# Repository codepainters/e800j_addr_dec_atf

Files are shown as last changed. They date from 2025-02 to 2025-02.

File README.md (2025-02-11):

# PROM replacement for Elwro 800 Junior - ATF1502ASL SMD variant

Elwro 800 Junior uses two `SN74S474` 512x8 PROMs as IO and memory address decoders. These PROMs are increasingly difficult to obtain (and program), this project provides a plug-in replacement for both address decoders based on `ATF1502ASL` CPLD in `TQFP-44` package.

Note: there is [another version](https://github.com/codepainters/e800j_addr_dec_gal/) using `GAL16V8` in `DIL-20`. 

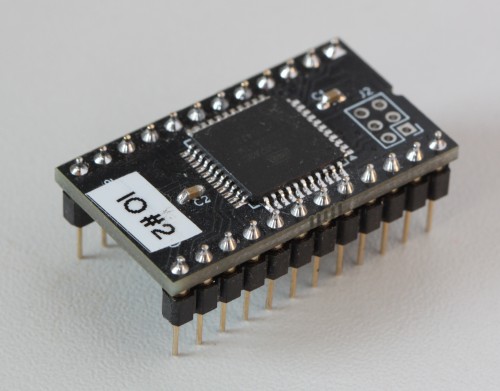
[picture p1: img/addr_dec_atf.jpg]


Hardware files:

* [pcb](pcb) - schematic/PCB project in KiCAD 8 format
* PDF schematics - [color](pdf/addr_dec.pdf) and [black&white](pdf/addr_dec_bw.pdf)
* [interactive BOM](addr_dec_atf_ibom.html) file (you have to download it and open locally)
* Gerber files (in a [jlcpcb](https://jlcpcb.com/)-compatible ZIP format):
  * [addr\_dec\_atf.zip](gerbers/addr_dec_atf.zip) - single PCB
  * [addr\_dec\_atf\_panel.zip](gerbers/addr_dec_atf_panel.zip) - two PCBs panelized

For bitstream files and programming instructions go to [bitstreams](bitstreams).

Under [src](src) you can find Quartus projects for I/O and MEM decoders (look there for details).

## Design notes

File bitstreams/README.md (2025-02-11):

# Bitstreams

The `ATF1502ASL` can be programmed using [OpenOCD](https://openocd.sourceforge.io/) (or any other software handling `.svf` files) with a supported `JTAG` interface. I have successfully programmed the chips using a `Segger J-Link v8` clone. 

`JTAG` connector `J2` pin-out (you have to provide +5V supply):

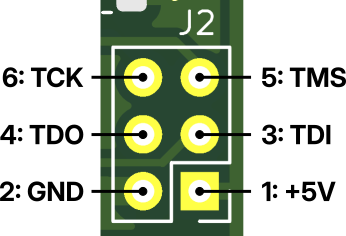
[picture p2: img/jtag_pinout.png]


## Files

The `ocd.sh` shell script is a wrapper around `openocd`, it takes a `svf` file name as its only parameter, e.g.:

```sh
$ ./ocd.sh addr_dec_io.svf
```

If you want to use other JTAG probe, edit the file accordingly (look for `-c "interface jlink"`).

The following `svf` files are available:
* `addr_dec_io.svf` - for I/O address decoder
* `addr_dec_mem.svf ` - for memory address decoder
* `atf1502asl_erase.svf` - helper file for erasing the `ATF1502ASL` chip

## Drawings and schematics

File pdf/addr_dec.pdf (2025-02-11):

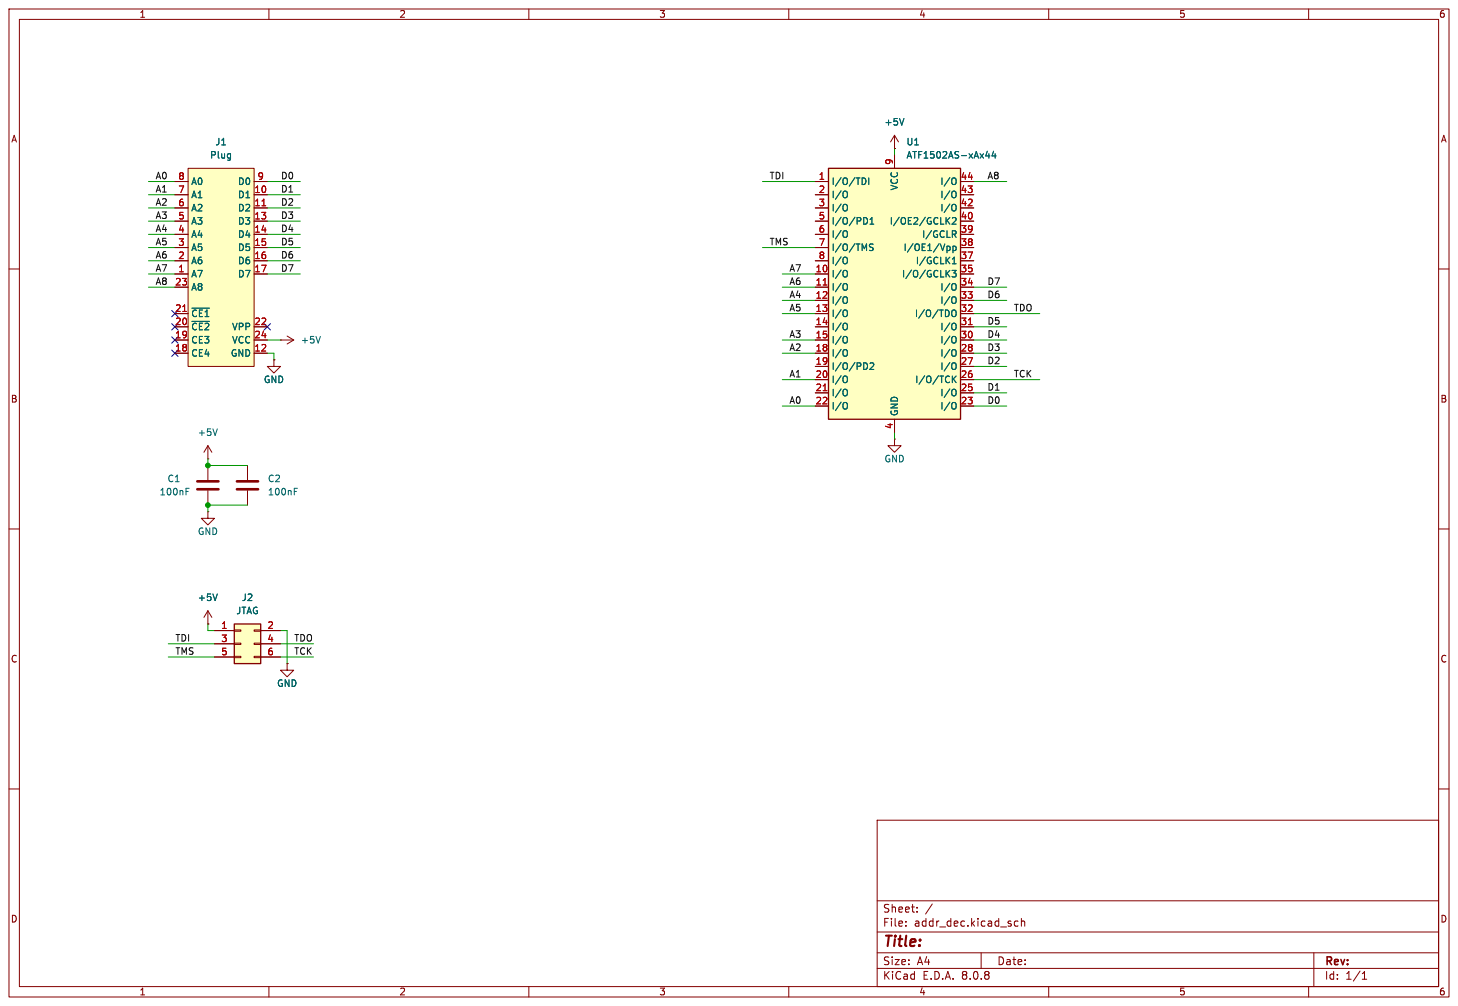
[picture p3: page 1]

Id: 1/1 Title: File: addr_dec.kicad_sch Sheet: / C2

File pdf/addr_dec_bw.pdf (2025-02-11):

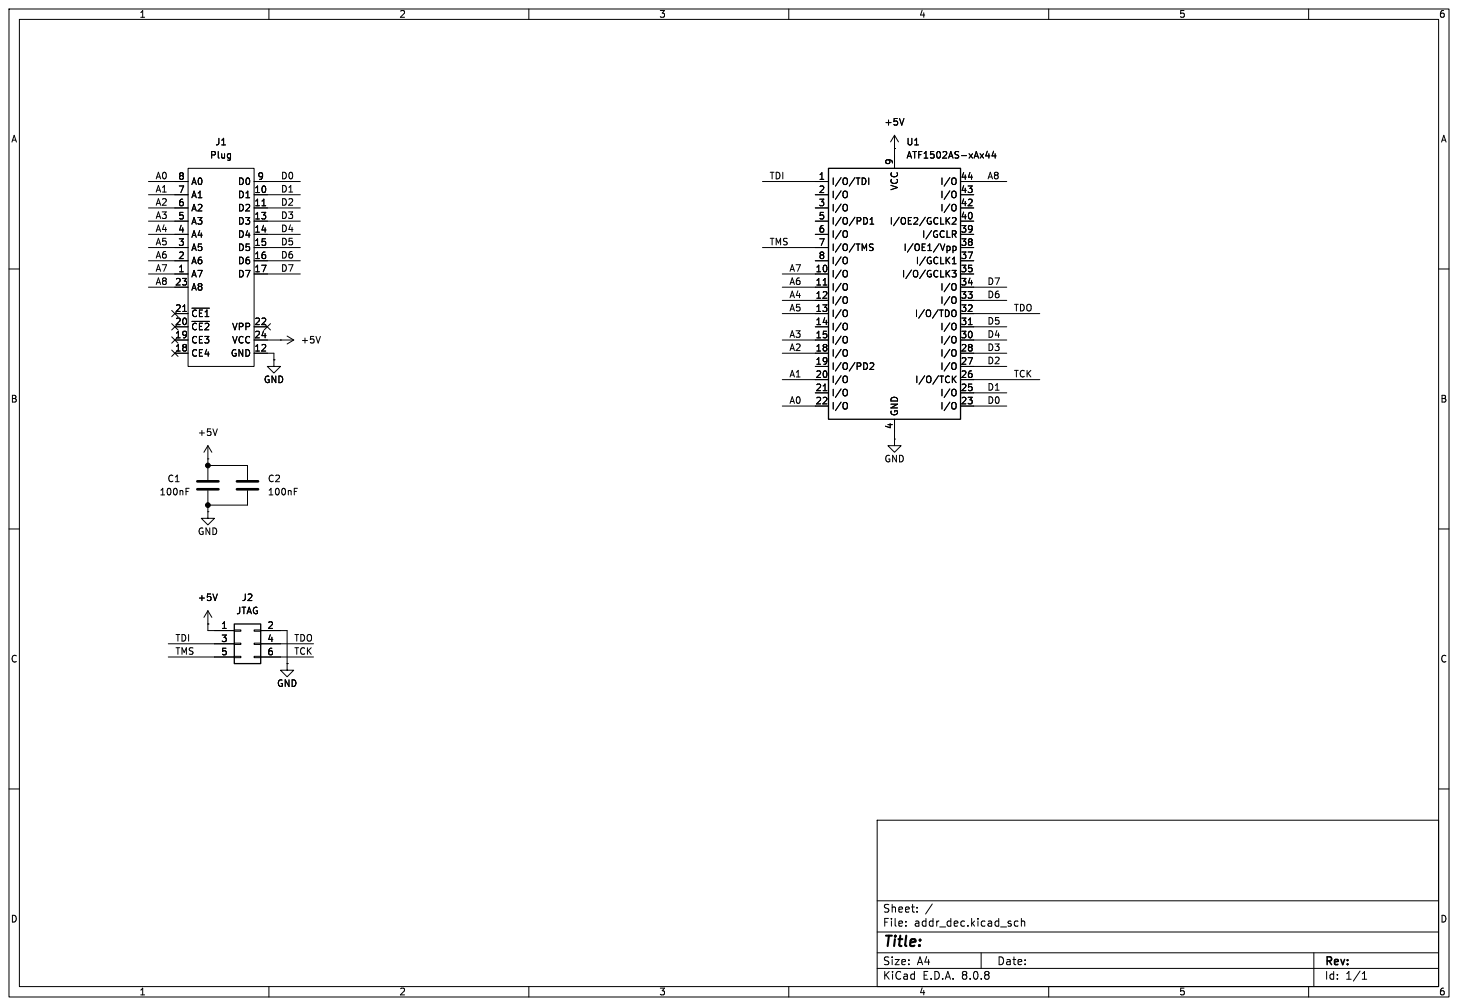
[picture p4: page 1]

Id: 1/1 Title: File: addr_dec.kicad_sch Sheet: / C2

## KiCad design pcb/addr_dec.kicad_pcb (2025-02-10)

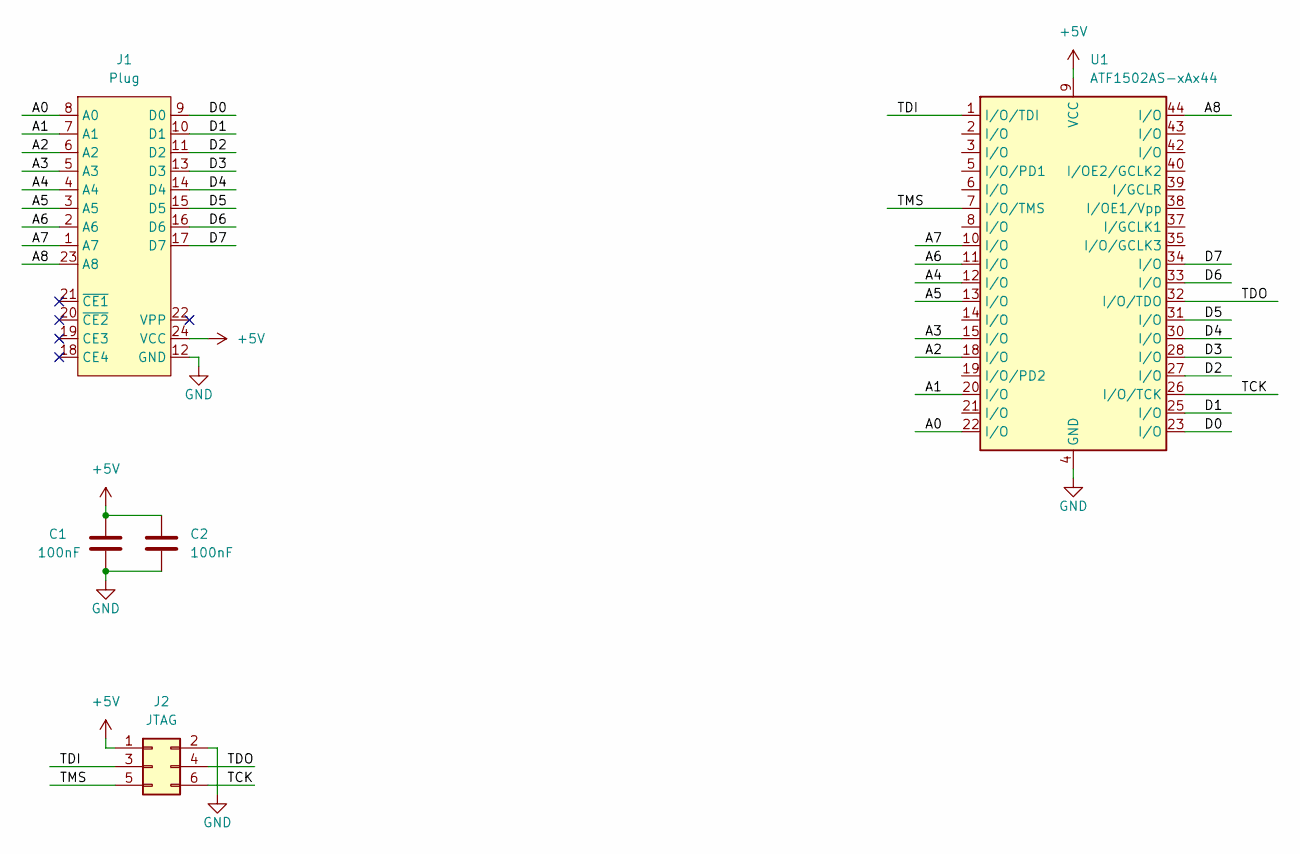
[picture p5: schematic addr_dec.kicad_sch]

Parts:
C1, C2: 100nF; C_0603_1608Metric_Pad1.08x0.95mm_HandSolder
J1: Plug; DIP-24_W15.24mm
J2: JTAG; PinHeader_2x03_P2.00mm_Vertical
U1: ATF1502AS-xAx44; TQFP-44_10x10mm_P0.8mm

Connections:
+5V: C1.1, C2.1, J1.24 (VCC), J2.1, U1.9 (VCC), U1.17 (VCC), U1.29 (VCC), U1.41 (VCC)
/A0: J1.8 (A0), U1.22 (I/O)
/A1: J1.7 (A1), U1.20 (I/O)
/A2: J1.6 (A2), U1.18 (I/O)
/A3: J1.5 (A3), U1.15 (I/O)
/A4: J1.4 (A4), U1.12 (I/O)
/A5: J1.3 (A5), U1.13 (I/O)
/A6: J1.2 (A6), U1.11 (I/O)
/A7: J1.1 (A7), U1.10 (I/O)
/A8: J1.23 (A8), U1.44 (I/O)
/D0: J1.9 (D0), U1.23 (I/O)
/D1: J1.10 (D1), U1.25 (I/O)
/D2: J1.11 (D2), U1.27 (I/O)
/D3: J1.13 (D3), U1.28 (I/O)
/D4: J1.14 (D4), U1.30 (I/O)
/D5: J1.15 (D5), U1.31 (I/O)
/D6: J1.16 (D6), U1.33 (I/O)
/D7: J1.17 (D7), U1.34 (I/O)
/TCK: J2.6, U1.26 (I/O/TCK)
/TDI: J2.3, U1.1 (I/O/TDI)
/TDO: J2.4, U1.32 (I/O/TDO)
/TMS: J2.5, U1.7 (I/O/TMS)
GND: C1.2, C2.2, J1.12 (GND), J2.2, U1.4 (GND), U1.16 (GND), U1.24 (GND), U1.36 (GND)

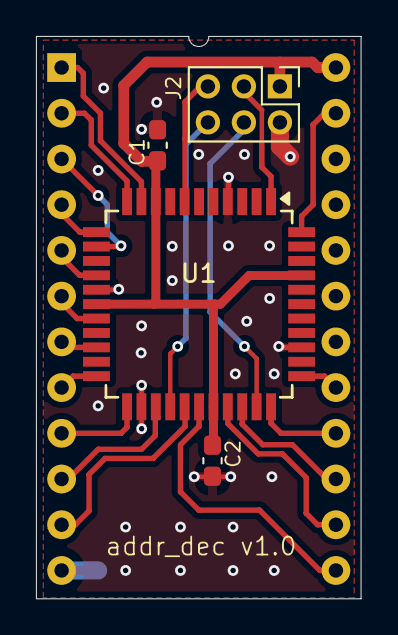
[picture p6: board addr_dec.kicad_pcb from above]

Board: 2 copper layers, 18.0 x 31.2 mm, 5 parts (0 on the bottom side), 23 nets.

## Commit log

2025-02-10 Initial import
    [addr_dec.kicad_pcb, addr_dec.kicad_sch]
2025-02-10 Added a PCB picture
2025-02-11 Added gerber files
2025-02-11 Schematic in PDF format
